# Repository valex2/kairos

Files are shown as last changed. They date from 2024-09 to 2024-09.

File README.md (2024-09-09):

# Kairos
The objective of this project was to develop a low-cost, portable AQI (Air Quality Index) monitor that logs key air quality metrics and stores them for long-term tracking.

This is driven by the worsening air quality due to climate change, particularly in regions like California where wildfires contribute to increased particulate matter in the atmosphere. Affordable sensors, such as Kairos, offer a scalable solution for monitoring air quality across large areas, providing national agencies with valuable data to analyze climate patterns, identify hotspots, and allocate resources more effectively.

A key advantage of Kairos is its portability and accessibility. Designed to be carried by individuals, it requires minimal infrastructure, reducing the overhead costs typically associated with large-scale environmental monitoring. This enables on-the-ground data collection and empowers individuals to better understand and respond to the air quality and environmental hazards in their immediate surroundings, while also meaningfully contributing to a larger, community or state-wide, AQI dataset. This version of Kairos serves as a proof of concept and has the following features:

1. Embedded compute
    1. The [**ATMEL SAMD51J19**](https://www.microchip.com/en-us/product/atsamd51j19a), an accessible chip, with 120MHz CPU, 256 KB RAM, and plenty of IO buses to handle sensor data and logging.
2. Instrumentation
    1. A [**Bosch SensorTech BME 688**](https://www.bosch-sensortec.com/products/environmental-sensors/gas-sensors/bme688/) — enabling high-accuracy pressure, humidity, temperature, Volatile Organic Compound (VOC) and Volatile Sulfur Compound (VSC) monitoring.
    2. An [**LTR-329ALS-01**](https://www.mouser.com/datasheet/2/239/Lite-On_LTR-329ALS-01%20DS_ver1.1-348647.pdf) — enabling visible- and IR-range light intensity measurements.
3. Communication modalities
    1. A **USB bus** — for communication with a host computer
    2. A **microSD** bus — for time-stamped ***logging*** of sensor values. Using an external SD card allows for prolonged operation without needing to pause logging
    3. A **display** — for on the go monitoring of sensor values
4. Two different power modes
    1. **USB Power** — embedded voltage regulators enable Kairos to be used in a stationary setting, say a roof of a building, for extended periods of time
    2. **Battery Power** — a 2500mAh LiPO and embedded charging circuitry allow Kairos to be taken on the go, for better-monitoring frequently travelled environments without requiring frequent charging.

While this version of Kairos demonstrates proof of concept, future iterations should expand its capabilities with the following features:

1. **UV Sensor**: To capture sun intensity across more (and more dangerous) wavelengths, providing a more comprehensive solar exposure assessment.
2. **GPS Module**: To enable precise tracking of Kairos’ location, facilitating the creation of accurate heatmaps for key AQI metrics.
3. **Bluetooth Syncing**: To allow seamless data transfer to mobile phones, removing the need to manually retrieve data from an SD card.
4. **A Centralized Server**: To aggregate data from multiple Kairos units, generating regional-level heatmaps and providing actionable insights from averaged data points across different areas.
5. **A rugged, waterproof, miniaturized shell for on the go use.**

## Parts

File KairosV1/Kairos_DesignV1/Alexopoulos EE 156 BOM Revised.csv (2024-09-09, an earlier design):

# | Reference | Qty (New) | Value | Footprint | DNP | Supplier 1 | Supplier 1 S/N | MFR | MFR S/N
1 | BOM1 | 6 | 10uH 0805 |  |  | https://www.digikey.com/en/products/detail/taiyo-yuden/LBR2012T100K/1788937 | 587-2045-1-ND | Taiyo Yuden | LBR2012T100K
2 | BOM2 | 20 | 0 Ohm Jumper |  |  | https://www.digikey.com/en/products/detail/stackpole-electronics-inc/RMCF0805ZT0R00/1756901 | RMCF0805ZT0R00CT-ND | Stackpole Electronics Inc | RMCF0805ZT0R00
3 | BOM3 | 16 | 10kO 0805 |  |  | https://www.digikey.com/en/products/detail/stackpole-electronics-inc/RMCF0805JT10K0/1757762 | RMCF0805JT10K0CT-ND | Stackpole Electronics Inc | RMCF0805JT10K0
4 | BOM4 | 6 | 20pF 0603 |  |  | https://www.digikey.com/en/products/detail/samsung-electro-mechanics/CL10C200JB8NNNC/3886845 | 1276-1187-1-ND | Samsung Electro-Mechanics | CL10C200JB8NNNC
5 | BOM5 | 6 | 24pF 0603 |  |  | https://www.digikey.com/en/products/detail/murata-electronics/GRM1885C1H240JA01D/586918 | 490-1412-1-ND | Murata Electronics | GRM1885C1H240JA01D
6 | BOM6 | 1 | LiPo 3.7V 2.5AH |  |  | https://www.adafruit.com/product/328 | 328
7 | BOM7 | 1 | OLED Display |  |  | https://www.digikey.com/en/products/detail/adafruit-industries-llc/938/5774238 | 1528-1512-ND | Adafruit Industries LLC | 938
8 | BOM8 | 6 | Header Pins |  |  | https://www.digikey.com/en/products/detail/adam-tech/PH1-09-UA/9830689 | 2057-PH1-09-UA-ND | Adam Tech | PH1-09-UA
9 | C1, C2 | 8 | 22pF | Capacitor_SMD:C_0603_1608Metric_Pad1.08x0.95mm_HandSolder |  | https://www.digikey.com/en/products/detail/kemet/C0603C220J5GAC7867/411055 | 399-C0603C220J5GAC7867CT-ND | KEMET | C0603C220J5GAC7867
10 | C3, C4, C21, C22 | 16 | 0.1u | Capacitor_SMD:C_0603_1608Metric_Pad1.08x0.95mm_HandSolder |  | https://www.digikey.com/en/products/detail/yageo/CC0603KRX7R7BB104/302822 | 311-1088-1-ND | YAGEO | CC0603KRX7R7BB104
11 | C5, C6, C7, C9, C12, C15, C16, C19, C20 | 36 | 1u | Capacitor_SMD:C_0603_1608Metric_Pad1.08x0.95mm_HandSolder |  | https://www.digikey.com/en/products/detail/yageo/CC0603KRX7R7BB105/2833611 | 311-1446-1-ND | YAGEO | CC0603KRX7R7BB105
12 | C8, C10, C13, C14, C18 | 20 | 10u | Capacitor_SMD:C_0603_1608Metric_Pad1.08x0.95mm_HandSolder |  | https://www.digikey.com/en/products/detail/taiyo-yuden/JMK107ABJ106MA-T/4970720 | 587-5869-1-ND | Taiyo Yuden | JMK107ABJ106MA-T
13 | C11, C17 | 8 | 4.7u | Capacitor_SMD:C_0603_1608Metric_Pad1.08x0.95mm_HandSolder |  | https://www.digikey.com/en/products/detail/samsung-electro-mechanics/CL10A475KP8NNNC/3886702 | 1276-1044-1-ND | Samsung Electro-Mechanics | CL10A475KP8NNNC
14 | D1 | 1 | WS2812B | LED_SMD:LED_WS2812B-2020_PLCC4_2.0x2.0mm |  | https://www.adafruit.com/product/4684 | WS2812B | Adafruit
15 | D2 | 3 | Schottky | Diode_SMD:D_SOD-123F |  | https://www.digikey.com/en/products/detail/onsemi/MBR120LSFT1G/1748986 | MBR120LSFT1GOSCT-ND | onsemi | MBR120LSFT1G
16 | D3 | 3 | LED | LED_SMD:LED_0805_2012Metric_Pad1.15x1.40mm_HandSolder |  | https://www.digikey.com/en/products/detail/qt-brightek-qtb/QBLP631-IG/4814682 | 1516-1084-1-ND | QT Brightek (QTB) | QBLP631-IG
20 | J4 | 2 | 3221-10-0300-00 | Connector:CONN10_3221-10-0300-00_CNC |  | https://www.digikey.com/en/products/detail/cnc-tech/3221-10-0300-00/4878946 | 1175-1735-ND | CNC Tech | 3221-10-0300-00
23 | J10 | 3 | 10118192-0001LF | digikey-footprints:USB_Micro_B_Female_10118192 |  | https://www.digikey.com/en/products/detail/amphenol-icc-fci/10118192-0001LF/2785387 | 609-4613-1-ND | Amphenol ICC (FCI) | 10118192-0001LF
24 | J13 | 3 | 1935161 | digikey-footprints:Terminal_Block_D1.3mm_P5mm |  | https://www.digikey.com/en/products/detail/phoenix-contact/1935161/568614?s=N4IgTCBcDa4OxwLQEYBsqkDkAiIC6AvkA | 277-1667-ND | Phoenix Contact | 1935161
25 | J14 | 3 | 2908-05WB-MG | digikey-footprints:MicroSD_2908-05WB-MG |  | https://www.digikey.com/en/products/detail/3m/2908-05WB-MG/1242497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 | 3M5607CT-ND | 3M | 2908-05WB-MG
29 | L1 | 4 | 31 Ohm at 100 MHz | Inductor_SMD:L_0805_2012Metric_Pad1.05x1.20mm_HandSolder |  | https://www.digikey.com/en/products/detail/laird-signal-integrity-products/HI0805Q310R-10/806633 | 240-2394-1-ND | Laird-Signal Integrity Products | HI0805Q310R-10
30 | Q1 | 4 | DMG3415U-7 | Package_TO_SOT_SMD:SOT-23-3 |  | https://www.digikey.com/en/products/detail/diodes-incorporated/DMG3415U-7/2052768 | DMG3415UDICT-ND | Diodes Incorporated | DMG3415U-7
31 | R1, R2, R5 | 12 | 100k | Resistor_SMD:R_0805_2012Metric_Pad1.20x1.40mm_HandSolder |  | https://www.digikey.com/en/products/detail/yageo/RC0805FR-07100KL/727544 | 311-100KCRCT-ND | YAGEO | RC0805FR-07100KL
32 | R3, R4, R7 | 12 | 10K | Resistor_SMD:R_0805_2012Metric_Pad1.20x1.40mm_HandSolder |  | https://www.digikey.com/en/products/detail/stackpole-electronics-inc/RMCF0805JT10K0/1757762 | RMCF0805JT10K0CT-ND | Stackpole Electronics Inc | RMCF0805JT10K0
33 | R6 | 4 | 1K | Resistor_SMD:R_0805_2012Metric_Pad1.20x1.40mm_HandSolder |  | https://www.digikey.com/en/products/detail/yageo/RC0805FR-071KL/727444 | 311-1.00KCRCT-ND | YAGEO | RC0805FR-071KL
34 | R8 | 4 | 2k | Resistor_SMD:R_0805_2012Metric_Pad1.20x1.40mm_HandSolder |  | https://www.digikey.com/en/products/detail/panasonic-electronic-components/ERJ-6ENF2001V/111341 | P2.00KCCT-ND | Panasonic Electronic Components | ERJ-6ENF2001V
35 | R9, R10, R21, R22 | 16 | 3.3k | Resistor_SMD:R_0805_2012Metric_Pad1.20x1.40mm_HandSolder |  | https://www.digikey.com/en/products/detail/stackpole-electronics-inc/RMCF0805JT3K30/1757905 | RMCF0805JT3K30CT-ND | Stackpole Electronics Inc | RMCF0805JT3K30
36 | R11, R12, R13, R14, R19, R20, R23, R24 | 32 | 0 | Resistor_SMD:R_0805_2012Metric_Pad1.20x1.40mm_HandSolder |  | https://www.digikey.com/en/products/detail/stackpole-electronics-inc/RMCF0805ZT0R00/1756901 | RMCF0805ZT0R00CT-ND | Stackpole Electronics Inc | RMCF0805ZT0R00
37 | R15, R16, R17, R18 | 16 | 47k | Resistor_SMD:R_0805_2012Metric_Pad1.20x1.40mm_HandSolder |  | https://www.digikey.com/en/products/detail/stackpole-electronics-inc/RMCF0805JT47K0/1757842 | RMCF0805JT47K0CT-ND | Stackpole Electronics Inc | RMCF0805JT47K0
38 | S1 | 4 | B3U-1000P | digikey-footprints:Switch_Tactile_SMD_B3U-1000P |  | https://www.digikey.com/en/products/detail/omron-electronics-inc-emc-div/B3U-1000P/1534338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 | SW1020CT-ND | Omron Electronics Inc-EMC Div | B3U-1000P
40 | U1 | 3 | ATSAMD51J19A-AUT | SAMD51J19A-AUT:TQFP64_PT_MCH |  | https://www.digikey.com/en/products/detail/microchip-technology/ATSAMD51J19A-AUT/7390302 | ATSAMD51J19A-AUTCT-ND | Microchip Technology | ATSAMD51J19A-AUT
41 | U2 | 3 | MCP73831 | Package_TO_SOT_SMD:SOT-23-5 |  | https://www.digikey.com/en/products/detail/microchip-technology/MCP73831T-2ACI-OT/964301 | MCP73831T-2ACI/OTCT-ND | Microchip Technology | MCP73831T-2ACI/OT
42 | U3 | 3 | AP2112k-3.3V | Package_TO_SOT_SMD:SOT-23-5 |  | https://www.digikey.com/en/products/detail/diodes-incorporated/AP2112K-3-3TRG1/4470746 | AP2112K-3.3TRG1DICT-ND | Diodes Incorporated | AP2112K-3.3TRG1
43 | U4 | 3 | LTR-329ALS-01 | LTR329:LTR-329ALS-01_LTO |  | https://www.digikey.com/en/products/detail/liteon/LTR-329ALS-01/4847334?s=N4IgTCBcDaIDYBcBOBmMBOEBdAvkA | 160-2160-1-ND | Lite-On Inc. | LTR-329ALS-01
44 | U5, U7 | 6 | 74AHC1G125 | Package_TO_SOT_SMD:SOT-23-5_HandSoldering |  | https://www.digikey.com/en/products/detail/texas-instruments/SN74AHC1G125DBVR/373801 | 296-8744-1-ND | Texas Instruments | SN74AHC1G125DBVR
45 | U6 | 3 | BME688 | Package_LGA:Bosch_LGA-8_3x3mm_P0.8mm_ClockwisePinNumbering |  | https://www.digikey.com/en/products/detail/bosch-sensortec/BME688/13681261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 | 828-BME688CT-ND | Bosch Sensortec | BME688
46 | X1 | 4 | 32.768kHz | Crystal:Crystal_SMD_3215-2Pin_3.2x1.5mm |  | https://www.digikey.com/en/products/detail/hosonic-electronic-co-ltd/ETST00327000JE/19908538 | 3186-ETST00327000JECT-ND | Hosonic Electronic Co., Ltd | ETST00327000JE

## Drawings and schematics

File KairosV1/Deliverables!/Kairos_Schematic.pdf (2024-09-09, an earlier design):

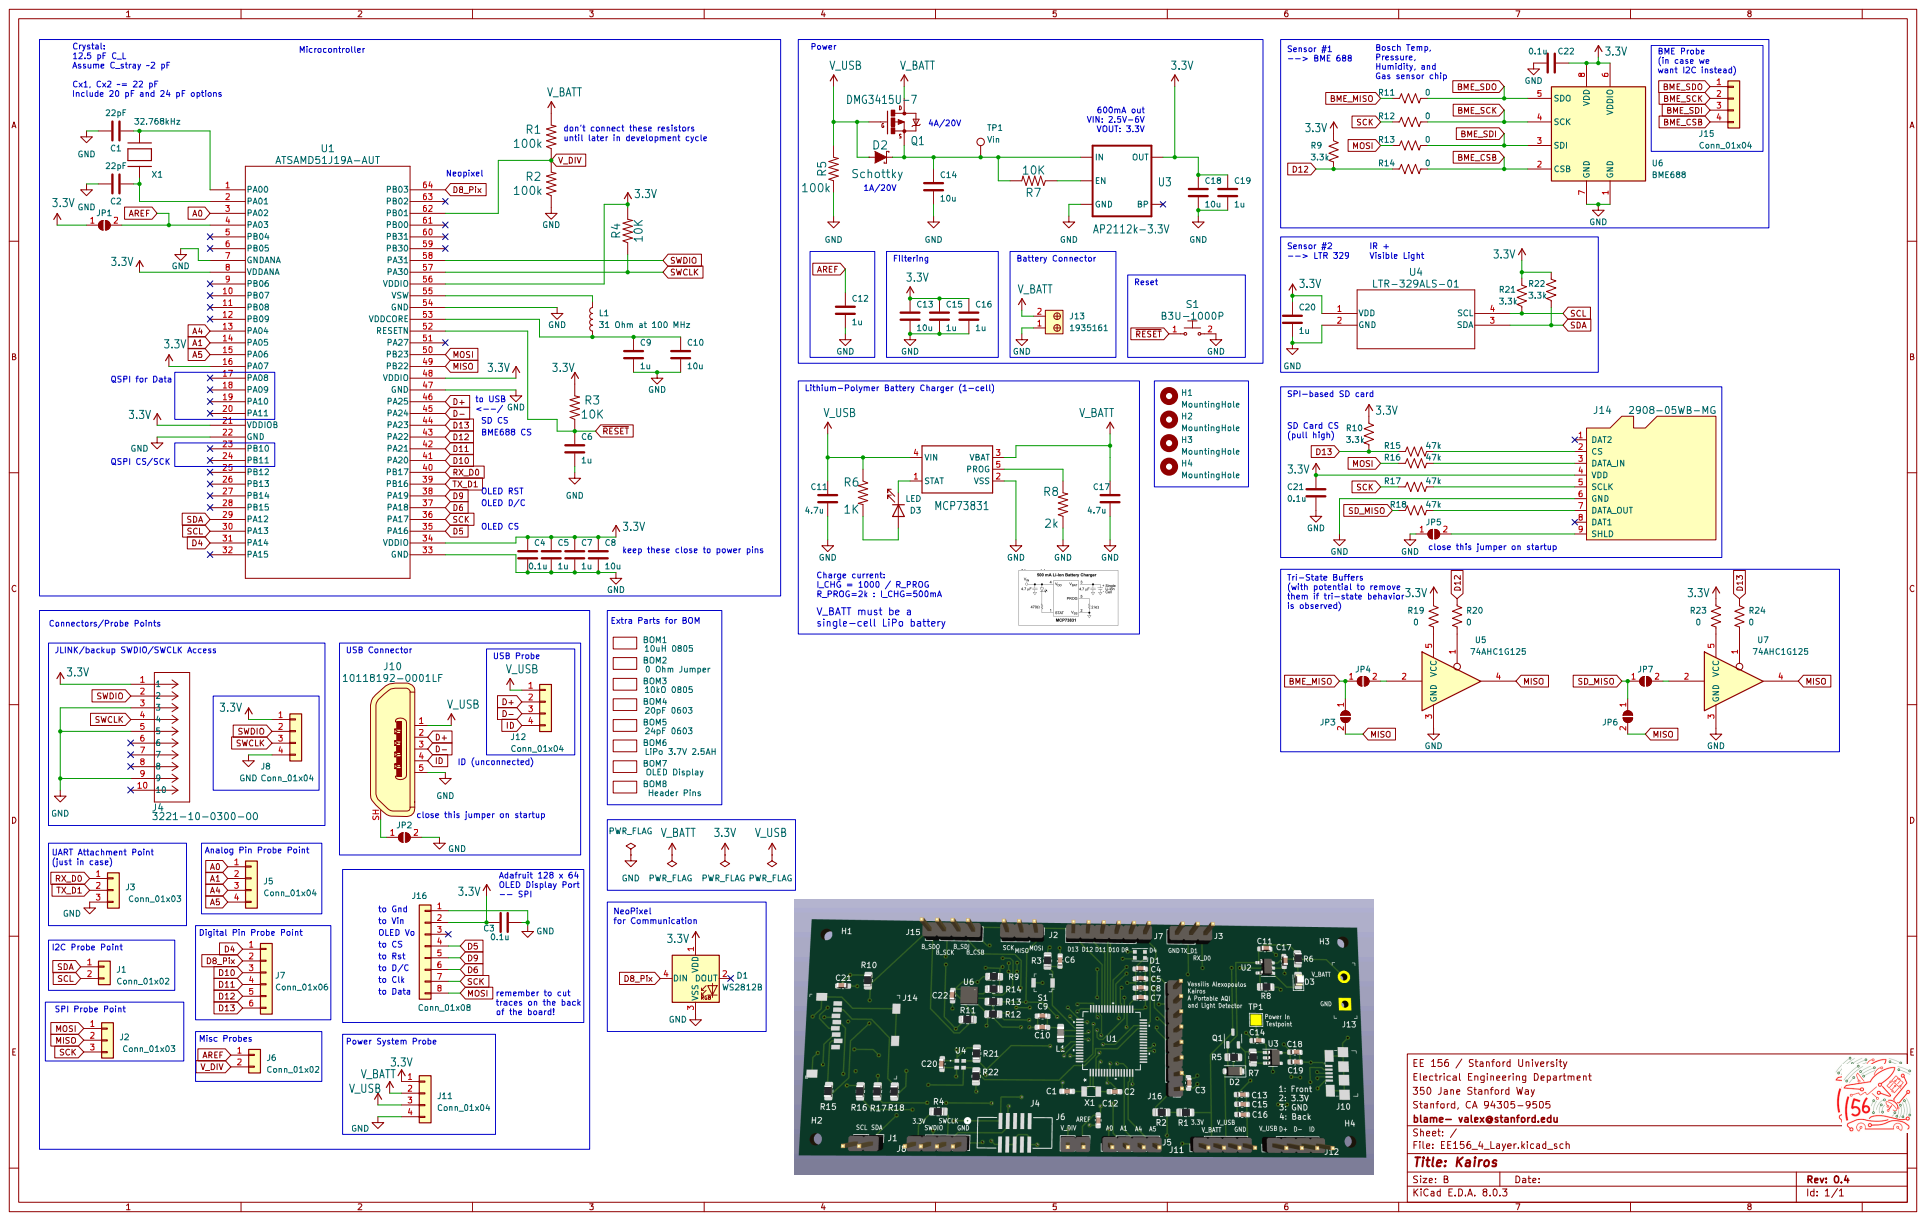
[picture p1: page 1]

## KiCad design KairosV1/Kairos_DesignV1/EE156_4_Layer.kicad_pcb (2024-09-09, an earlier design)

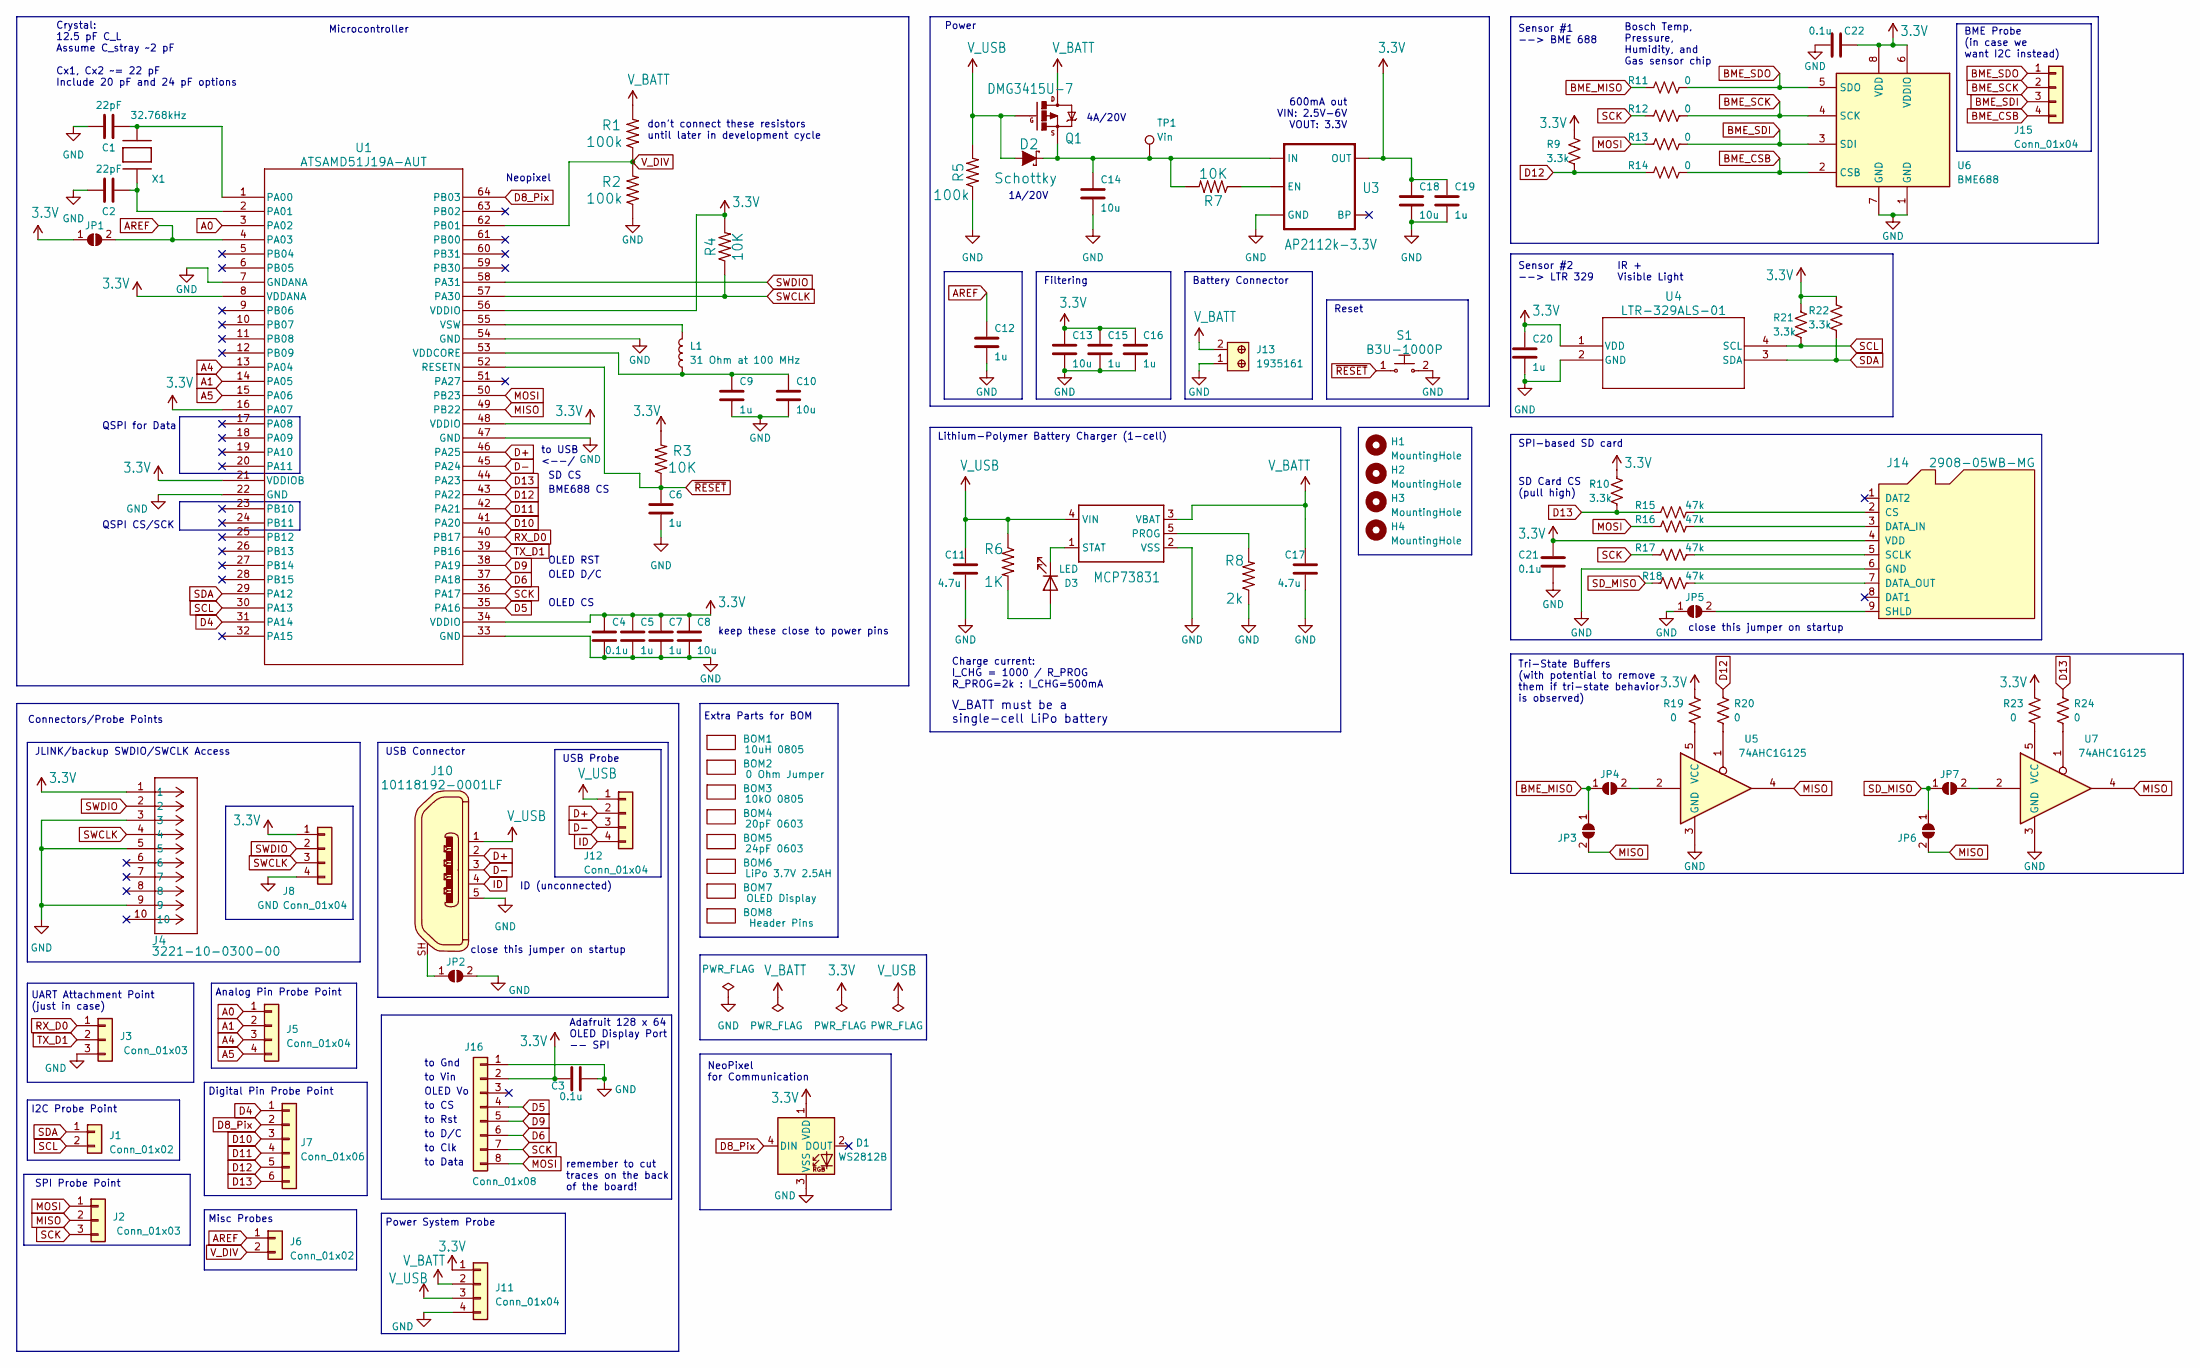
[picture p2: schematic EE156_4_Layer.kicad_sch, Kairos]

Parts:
BOM1: 10uH 0805
BOM2: 0 Ohm Jumper
BOM3: 10kO 0805
BOM4: 20pF 0603
BOM5: 24pF 0603
BOM6: LiPo 3.7V 2.5AH
BOM7: OLED Display
BOM8: Header Pins
C1, C2: 22pF; C_0603_1608Metric_Pad1.08x0.95mm_HandSolder
C3, C4, C21, C22: 0.1u; C_0603_1608Metric_Pad1.08x0.95mm_HandSolder
C5, C6, C7, C9, C12, C15, C16, C19, C20: 1u; C_0603_1608Metric_Pad1.08x0.95mm_HandSolder
C8, C10, C13, C14, C18: 10u; C_0603_1608Metric_Pad1.08x0.95mm_HandSolder
C11, C17: 4.7u; C_0603_1608Metric_Pad1.08x0.95mm_HandSolder
D1: WS2812B; LED_WS2812B-2020_PLCC4_2.0x2.0mm
D2: Schottky; D_SOD-123F
D3: LED; LED_0805_2012Metric_Pad1.15x1.40mm_HandSolder
H1, H2, H3, H4: MountingHole; MountingHole_2.1mm
J1, J6: Conn_01x02; PinHeader_1x02_P2.54mm_Vertical
J2, J3: Conn_01x03; PinHeader_1x03_P2.54mm_Vertical
J4: 3221-10-0300-00; CONN10_3221-10-0300-00_CNC
J5, J8, J11, J12, J15: Conn_01x04; PinHeader_1x04_P2.54mm_Vertical
J7: Conn_01x06; PinHeader_1x06_P2.54mm_Vertical
J10: 10118192-0001LF; USB_Micro_B_Female_10118192
J13: 1935161; Terminal_Block_D1.3mm_P5mm
J14: 2908-05WB-MG; MicroSD_2908-05WB-MG
J16: Conn_01x08; PinHeader_1x08_P2.54mm_Vertical
JP1, JP2, JP3, JP4, JP5, JP6, JP7: SolderJumper_2_Open; SolderJumper-2_P1.3mm_Open_Pad1.0x1.5mm
L1: 31 Ohm at 100 MHz; L_0805_2012Metric_Pad1.05x1.20mm_HandSolder
Q1: DMG3415U-7; SOT-23-3
R1, R2, R5: 100k; R_0805_2012Metric_Pad1.20x1.40mm_HandSolder
R3, R4, R7: 10K; R_0805_2012Metric_Pad1.20x1.40mm_HandSolder
R6: 1K; R_0805_2012Metric_Pad1.20x1.40mm_HandSolder
R8: 2k; R_0805_2012Metric_Pad1.20x1.40mm_HandSolder
R9, R10, R21, R22: 3.3k; R_0805_2012Metric_Pad1.20x1.40mm_HandSolder
R11, R12, R13, R14, R19, R20, R23, R24: 0; R_0805_2012Metric_Pad1.20x1.40mm_HandSolder
R15, R16, R17, R18: 47k; R_0805_2012Metric_Pad1.20x1.40mm_HandSolder
S1: B3U-1000P; Switch_Tactile_SMD_B3U-1000P
TP1: Vin; TestPoint_Pad_2.0x2.0mm
U1: ATSAMD51J19A-AUT; TQFP64_PT_MCH
U2: MCP73831; SOT-23-5
U3: AP2112k-3.3V; SOT-23-5
U4: LTR-329ALS-01; LTR-329ALS-01_LTO
U5, U7: 74AHC1G125; SOT-23-5_HandSoldering
U6: BME688; Bosch_LGA-8_3x3mm_P0.8mm_ClockwisePinNumbering
X1: 32.768kHz; Crystal_SMD_3215-2Pin_3.2x1.5mm

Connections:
3.3V: C3.1, C4.1, C5.1, C7.1, C8.1, C13.1, C15.1, C16.1, C18.1, C19.1, C20.1, C21.1, C22.1, D1.1 (VDD), J4.1, J8.1, J11.1, J14.4 (VDD), J16.2, JP1.1 (A), R3.2, R4.2, R9.1, R10.1, R19.2, R21.1, R22.1, R23.2, U1.8 (VDDANA), U1.16 (PA07), U1.21 (VDDIOB), U1.34 (VDDIO), U1.48 (VDDIO), U1.56 (VDDIO), U3.5 (OUT), U4.1 (VDD), U6.6 (VDDIO), U6.8 (VDD)
A0: J5.1, U1.3 (PA02)
A1: J5.2, U1.14 (PA05)
A4: J5.3, U1.13 (PA04)
A5: J5.4, U1.15 (PA06)
AREF: C12.1, J6.1, JP1.2 (B), U1.4 (PA03)
BME_CSB: J15.4, R14.2, U6.2 (CSB)
BME_MISO: JP3.1 (A), JP4.1 (A), R11.1
BME_SCK: J15.2, R12.2, U6.4 (SCK)
BME_SDI: J15.3, R13.2, U6.3 (SDI)
BME_SDO: J15.1, R11.2, U6.5 (SDO)
D4: J7.1, U1.31 (PA14)
D5: J16.4, U1.35 (PA16)
D6: J16.6, U1.37 (PA18)
D8_Pix: D1.4 (DIN), J7.2, U1.64 (PB03)
D9: J16.5, U1.38 (PA19)
D10: J7.3, U1.41 (PA20)
D11: J7.4, U1.42 (PA21)
D12: J7.5, R9.2, R14.1, R20.2, U1.43 (PA22)
D13: J7.6, R10.2, R15.1, R24.2, U1.44 (PA23)
D+: J10.2, J12.2, U1.46 (PA25)
D-: J10.3, J12.3, U1.45 (PA24)
GND: C1.1, C2.1, C3.2, C4.2, C5.2, C6.2, C7.2, C8.2, C9.2, C10.2, C11.2, C12.2, C13.2, C14.2, C15.2, C16.2, C17.2, C18.2, C19.2, C20.2, C21.2, C22.2, D1.3 (VSS), J3.3, J4.3, J4.5, J4.9, J8.4, J10.5, J11.4, J13.1, J14.6 (GND), J16.1, JP2.2 (B), JP5.1 (A), R2.1, R5.1, R8.1, S1.2, U1.7 (GNDANA), U1.22 (GND), U1.33 (GND), U1.47 (GND), U1.54 (GND), U2.2 (VSS), U3.2 (GND), U4.2 (GND), U5.3 (GND), U6.1 (GND), U6.7 (GND), U7.3 (GND)
ID: J10.4, J12.4
MISO: J2.2, JP3.2 (B), JP6.2 (B), U1.49 (PB22), U5.4, U7.4
MOSI: J2.1, J16.8, R13.1, R16.1, U1.50 (PB23)
unnamed: D3.2 (A), R6.2
unnamed: D3.1 (K), U2.1 (STAT)
unnamed: J14.2 (CS), R15.2
unnamed: J14.3 (DATA_IN), R16.2
unnamed: J14.7 (DATA_OUT), R18.2
unnamed: J14.5 (SCLK), R17.2
unnamed: J14.9 (SHLD), JP5.2 (B)
unnamed: J10.SH, JP2.1 (A)
unnamed: JP4.2 (B), U5.2
unnamed: JP7.2 (B), U7.2
unnamed: C14.1, D2.1, Q1.2 (S), R7.2, TP1.1, U3.1 (IN)
unnamed: R20.1, U5.1
unnamed: R24.1, U7.1
unnamed: C1.2, U1.1 (PA00), X1.1
unnamed: C2.2, U1.2 (PA01), X1.2
unnamed: C9.1, C10.1, L1.1, U1.53 (VDDCORE)
unnamed: L1.2, U1.55 (VSW)
unnamed: R8.2, U2.5 (PROG)
unnamed: R7.1, U3.3 (EN)
unnamed: R19.1, U5.5 (VCC)
unnamed: R23.1, U7.5 (VCC)
RX_D0: J3.1, U1.40 (PB17)
SCK: J2.3, J16.7, R12.1, R17.1, U1.36 (PA17)
SCL: J1.2, R21.2, U1.30 (PA13), U4.4 (SCL)
SDA: J1.1, R22.2, U1.29 (PA12), U4.3 (SDA)
SD_MISO: JP6.1 (A), JP7.1 (A), R18.1
SWCLK: J4.4, J8.3, R4.1, U1.57 (PA30)
SWDIO: J4.2, J8.2, U1.58 (PA31)
TX_D1: J3.2, U1.39 (PB16)
V_BATT: C17.1, J11.2, J13.2, Q1.3 (D), R1.2, U2.3 (VBAT)
V_DIV: J6.2, R1.1, R2.2, U1.62 (PB01)
V_USB: C11.1, D2.2, J10.1, J11.3, J12.1, Q1.1 (G), R5.2, R6.1, U2.4 (VIN)
~RESET: C6.1, R3.1, S1.1, U1.52 (RESETN)

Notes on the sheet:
Digital Pin Probe Point
Charge current: I_CHG = 1000 / R_PROG R_PROG=2k : I_CHG=500mA
to Gnd
Reset
Microcontroller
USB Connector
600mA out VIN: 2.5V-6V VOUT: 3.3V
SD Card CS (pull high)
don't connect these resistors until later in development cycle
IR + Visible Light
to Rst
UART Attachment Point (just in case)
OLED RST
Connectors/Probe Points
1A/20V
I2C Probe Point
to CS
to D/C
JLINK/backup SWDIO/SWCLK Access
OLED Vo
Power
Crystal: 12.5 pF C_L Assume C_stray ~2 pF Cx1, Cx2 ~= 22 pF Include 20 pF and 24 pF options
Misc Probes
Adafruit 128 x 64 OLED Display Port -- SPI
BME Probe (in case we want I2C instead)
ID (unconnected)
Tri-State Buffers (with potential to remove them if tri-state behavior is observed)
USB Probe
Sensor #1 --> BME 688
OLED CS
NeoPixel for Communication
V_BATT must be a single-cell LiPo battery
BME688 CS
Power System Probe
QSPI CS/SCK
SPI-based SD card
to Data
remember to cut traces on the back of the board!
to Clk
to Vin

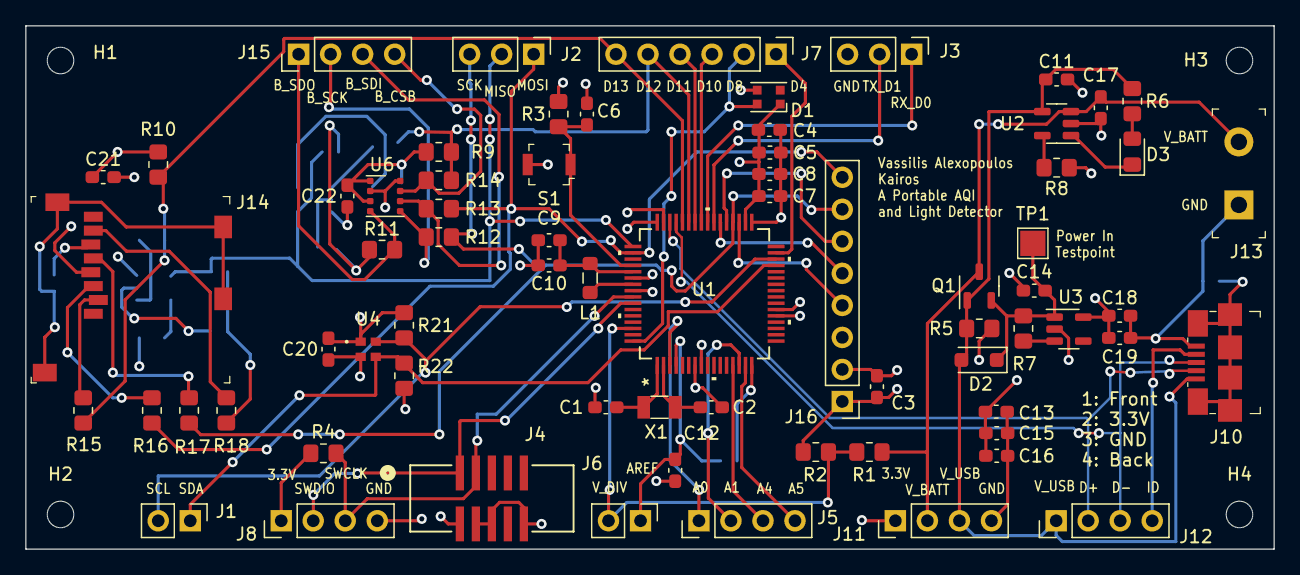
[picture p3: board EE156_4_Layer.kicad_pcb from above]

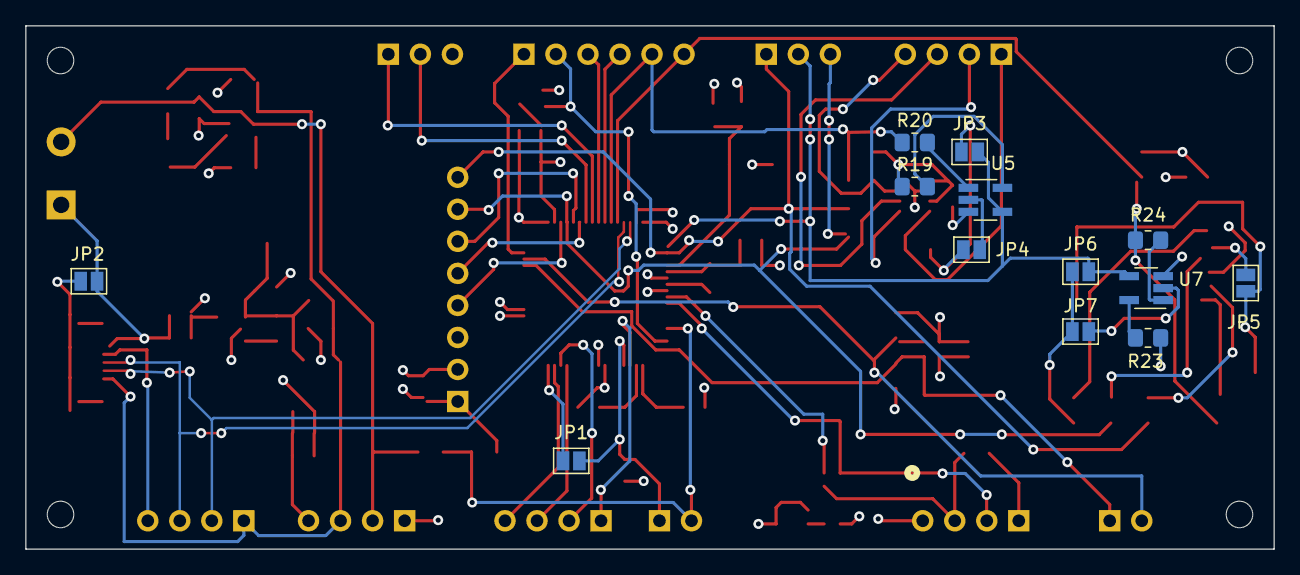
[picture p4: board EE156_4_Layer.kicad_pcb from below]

Board: 4 copper layers, 99.0 x 41.5 mm, 87 parts (13 on the bottom side), 59 nets.

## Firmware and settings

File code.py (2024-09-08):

import digitalio
import board
import time
import adafruit_ssd1306
import adafruit_bme680
import adafruit_ltr329_ltr303
import adafruit_sdcard
import storage
import busio
import gfx  # graphics and shape rendering module
from digitalio import DigitalInOut

i2c = busio.I2C(scl = board.PA13, sda = board.PA12)
light_sensor = adafruit_ltr329_ltr303.LTR329(i2c)

spi = busio.SPI(board.PA17, MOSI=board.PB23, MISO=board.PB22)  # init the SPI bus
reset_pin = DigitalInOut(board.PA19)  # board pin D9
cs_pin = DigitalInOut(board.PA16)  # board pin D5
dc_pin = DigitalInOut(board.PA18)  # board pin D6
oled = adafruit_ssd1306.SSD1306_SPI(128, 64, spi, dc_pin, reset_pin, cs_pin)  # 128 x 64 pixel SSD1306 display

graphics = gfx.GFX(128, 64, oled.pixel)  # initiate gfx class

AQI_cs_pin = DigitalInOut(board.PA22)  # board pin D12
AQI_sensor = adafruit_bme680.Adafruit_BME680_SPI(spi, AQI_cs_pin)
AQI_sensor.sea_level_pressure = 1013.25  # set the sea level pressure

SD_card_CS = DigitalInOut(board.PA23)
SD_card = adafruit_sdcard.SDCard(spi, SD_card_CS)
vfs = storage.VfsFat(SD_card)
storage.mount(vfs, "/sd")

pin_D10 = digitalio.DigitalInOut(board.PA20)
pin_D10.direction = digitalio.Direction.OUTPUT

pin_NEO = digitalio.DigitalInOut(board.PB03)
pin_NEO.direction = digitalio.Direction.OUTPUT

while True:

    # access the pressure readings
    temperature = AQI_sensor.temperature
    gas = AQI_sensor.gas
    relative_humidity = AQI_sensor.relative_humidity
    pressure = AQI_sensor.pressure
    altitude = AQI_sensor.altitude
    IR = light_sensor.ir_light
    vis_plus_IR = light_sensor.visible_plus_ir_light
    vis = vis_plus_IR - IR

    oled.fill(0)
    oled.text(f"Temp: {temperature:.1f} C", 0, 0, 1)
    oled.text(f"Gas: {gas} ohms", 0, 10, 1)
    oled.text(f"Humidity: {relative_humidity:.1f} %", 0, 20, 1)
    oled.text(f"Pressure: {pressure:.1f} hPa", 0, 30, 1)
    oled.text(f"Altitude: {altitude:.1f} m", 0, 40, 1)
    oled.text(f"Vis:{vis:.1f}|IR:{IR:.1f} lux︎", 0, 50, 1)
    oled.show()

    pin_D10.value = True
    pin_NEO.value = True

    time.sleep(0.1)

    pin_D10.value = False
    pin_NEO.value = False

    time.sleep(0.1)

# print(pin_D10.value)
# print("Done printing")

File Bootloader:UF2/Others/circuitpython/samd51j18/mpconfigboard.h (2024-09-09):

#define MICROPY_HW_BOARD_NAME "Adafruit Feather M4 Express"
#define MICROPY_HW_MCU_NAME "samd51j18"

#define CIRCUITPY_MCU_FAMILY samd51

// Rev E

// #define MICROPY_HW_LED_STATUS   (&pin_PA23)
// #define MICROPY_HW_NEOPIXEL (&pin_PB03)

#define BOARD_HAS_CRYSTAL 1

#define DEFAULT_I2C_BUS_SCL (&pin_PA13)
#define DEFAULT_I2C_BUS_SDA (&pin_PA12)

#define DEFAULT_SPI_BUS_SCK (&pin_PA17)
#define DEFAULT_SPI_BUS_MOSI (&pin_PB23)
#define DEFAULT_SPI_BUS_MISO (&pin_PB22)

#define DEFAULT_UART_BUS_RX (&pin_PB17)
#define DEFAULT_UART_BUS_TX (&pin_PB16)

// USB is always used internally so skip the pin objects for it.
#define IGNORE_PIN_PA24     1
#define IGNORE_PIN_PA25     1

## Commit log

2024-09-08 update display, fixed SD card
    [code.py]
2024-09-08 SD card working
    [test1.csv, test2.csv, test_temp_light.csv]
2024-09-09 bootloader and uf2 addition
    [long_record.csv, video.csv]
2024-09-09 big data
    [packard_to_west_lag_night.csv]
2024-09-09 report and boards
    [Alexopoulos EE 156 BOM Revised.csv, Alexopoulos EE 156 BOM.csv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]
2024-12-25 beginnning v2
    [Alexopoulos EE 156 BOM Revised.csv, Alexopoulos EE 156 BOM.csv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]
2024-12-25 beginning v2
    [Alexopoulos EE 156 BOM Revised.csv, Alexopoulos EE 156 BOM.csv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]
